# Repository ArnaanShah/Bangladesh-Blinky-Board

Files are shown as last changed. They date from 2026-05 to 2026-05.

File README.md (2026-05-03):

 # Bangladesh-Blinky-Board  
A Simple LED chaser in the shape of the flag of Bangladesh based on the Blinky Board tutorial from Stasis. The 10 red LEDs are arranged along the circle of the Bangladesh flag. There is a red 3d printed part to cover the white silkscreen and make the PCB resemble the flag more. This was a very fun simpler project to make and I liked that I could include something personal to me in it. It taught me how to use analog sensors. 

# Setup
The setup is very quick and can be done in 4 steps:

1. Order your PCB from [JLCPCB](https://jlcpcb.com)
2. Solder the components onto the board
3. Place the 3d printed circle on top of the LED ring
4. Power on your blinky board!

# PCB
The PCB was made in KiCad and it was very easy because most of the instructions were given by the tutorial. The schematic was a bit tricky because some of the individual part schematics looked different, but I was able to figure it out. Making the layout of the PCB made me learn how to use the array tool in KiCad. The routing was simple and I tried arranging the rest of the components in a way that would look nice. 

Schematic: 


PCB:


3d view:



# 3d Prints
There is one 3d printed part of the board and it's to make it look nicer and more accurate to the flag. It's a red circle that goes ontop of the LEDs that I made in Fusion360.

Images:



# BOM
There's only really 3 things you need for this build. You need the Blinky Board kit from Hackclub, the 3d printed circle, and a custom PCB.

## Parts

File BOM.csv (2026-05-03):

Name | Amount | Where to Get
Blinky Board Kit | 1 | Hackclub
PCB | 1 | JLCPCB
3d Printed circle | 1 | N/A

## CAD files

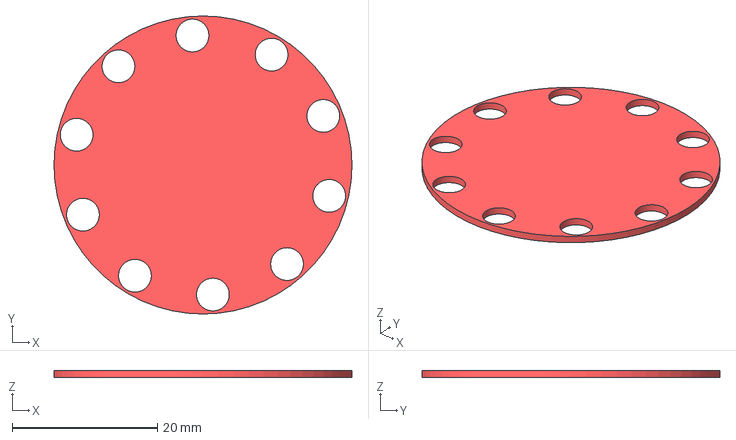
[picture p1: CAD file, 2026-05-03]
CAD/BangladeshFlagCircle.step
41.0 x 41.0 x 1.00 mm

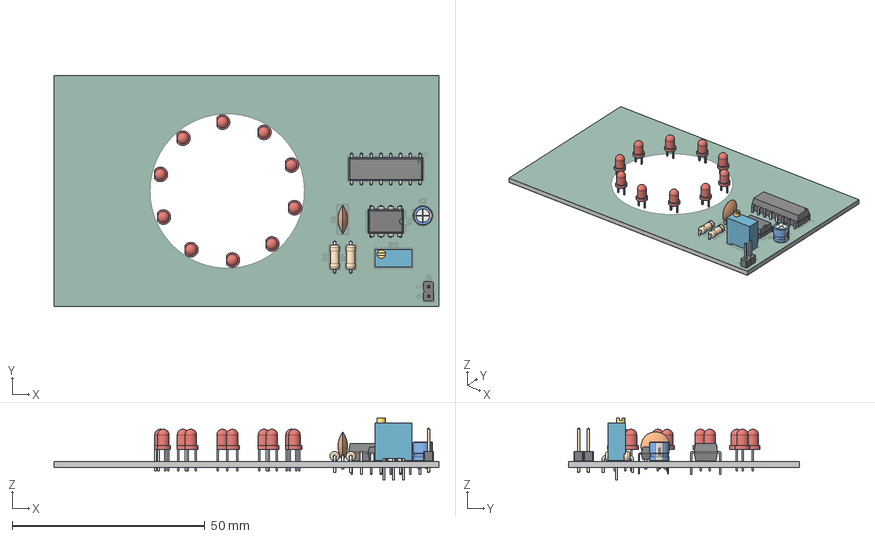
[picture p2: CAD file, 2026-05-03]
PCB/Extras/BangladeshBlinkyBoard.step
100.0 x 60.0 x 16.0 mm
LED_D3.0mm x 10
PinHeader_1x02_P2.54mm_Vertical
T93YA
C_Disc_D7.5mm_W2.5mm_P5.00mm
Body001 (Mirror #1) x 9
R_Axial_DIN0207_L6.3mm_D2.5mm_P7.62mm_Horizontal x 2
CP_Radial_D5.0mm_P2.00mm
DIP-8_W7.62mm
LightningBlinkyBoard_silkscreen x 2
LightningBlinkyBoard_soldermask x 2
LightningBlinkyBoard_PCB

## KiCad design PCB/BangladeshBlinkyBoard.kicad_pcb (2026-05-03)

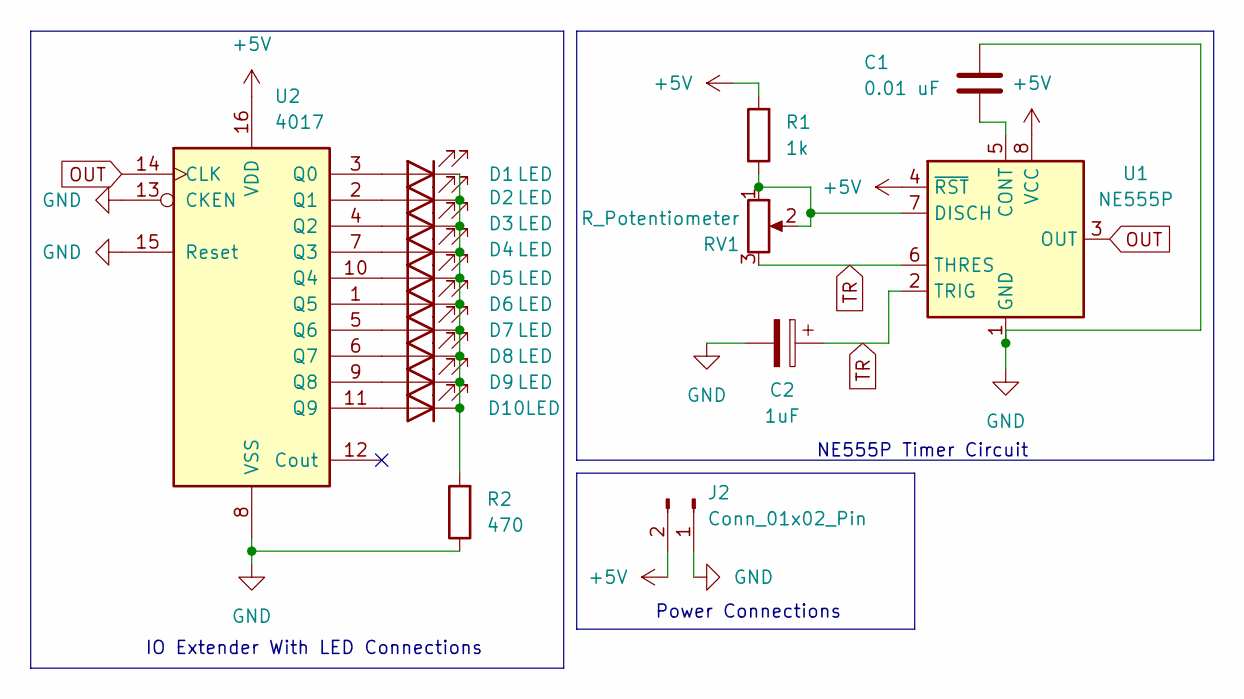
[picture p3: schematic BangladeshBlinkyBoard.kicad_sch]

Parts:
C1: 0.01 uF; C_Disc_D7.5mm_W2.5mm_P5.00mm
C2: 1uF; CP_Radial_D5.0mm_P2.00mm
D1, D2, D3, D4, D5, D6, D7, D8, D9, D10: LED; LED_D3.0mm
J2: Conn_01x02_Pin; PinHeader_1x02_P2.54mm_Vertical
R1: 1k; R_Axial_DIN0207_L6.3mm_D2.5mm_P7.62mm_Horizontal
R2: 470; R_Axial_DIN0207_L6.3mm_D2.5mm_P7.62mm_Horizontal
RV1: R_Potentiometer; Potentiometer_Vishay_T93YA_Vertical
U1: NE555P; DIP-8_W7.62mm
U2: 4017; N16

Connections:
+5V: J2.2, R1.2, U1.4 (~RST), U1.8 (VCC), U2.16 (VDD)
GND: C1.2, C2.2, J2.1, R2.1, U1.1 (GND), U2.8 (VSS), U2.13 (CKEN), U2.15 (Reset)
unnamed: D1.2 (A), U2.3 (Q0)
unnamed: D1.1 (K), D2.1 (K), D3.1 (K), D4.1 (K), D5.1 (K), D6.1 (K), D7.1 (K), D8.1 (K), D9.1 (K), D10.1 (K), R2.2
unnamed: D2.2 (A), U2.2 (Q1)
unnamed: D3.2 (A), U2.4 (Q2)
unnamed: D4.2 (A), U2.7 (Q3)
unnamed: D5.2 (A), U2.10 (Q4)
unnamed: D6.2 (A), U2.1 (Q5)
unnamed: D7.2 (A), U2.5 (Q6)
unnamed: D8.2 (A), U2.6 (Q7)
unnamed: D9.2 (A), U2.9 (Q8)
unnamed: D10.2 (A), U2.11 (Q9)
unnamed: C1.1, U1.5 (CONT)
unnamed: R1.1, RV1.1, RV1.2, U1.7 (DISCH)
OUT: U1.3 (OUT), U2.14 (CLK)
TR: C2.1, RV1.3, U1.2 (TRIG), U1.6 (THRES)

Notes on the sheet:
NE555P Timer Circuit
Power Connections
IO Extender With LED Connections

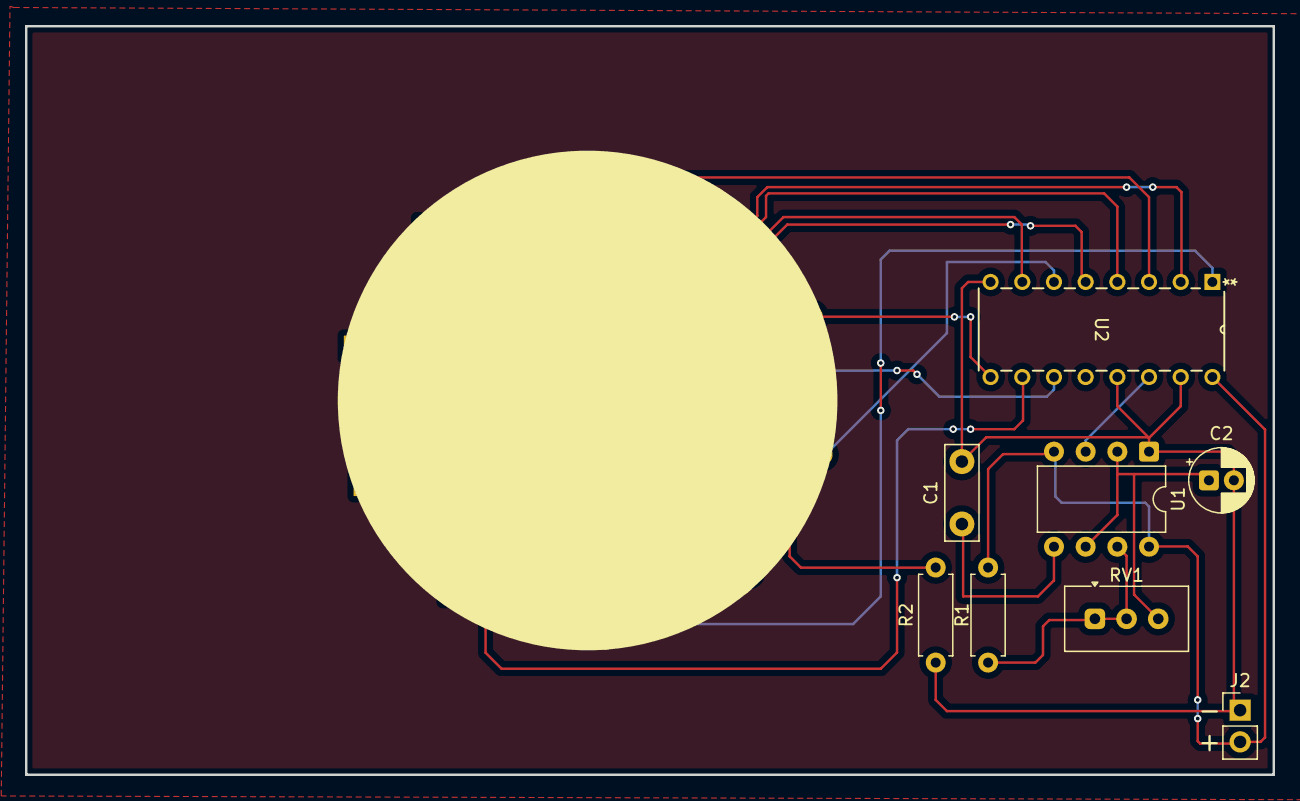
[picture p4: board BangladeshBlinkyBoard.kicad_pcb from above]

Board: 2 copper layers, 100.0 x 60.0 mm, 18 parts (0 on the bottom side), 17 nets.

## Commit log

2026-05-03 Adding all required files PCB, CAD, BOM, Manufacturing
    [BOM.csv, BangladeshBlinkyBoard.kicad_pcb, BangladeshBlinkyBoard.kicad_sch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]
2026-05-03 Enhance README with project details and instructions
    Expanded the README with detailed project description, setup instructions, PCB design process, 3D print information, and BOM.
